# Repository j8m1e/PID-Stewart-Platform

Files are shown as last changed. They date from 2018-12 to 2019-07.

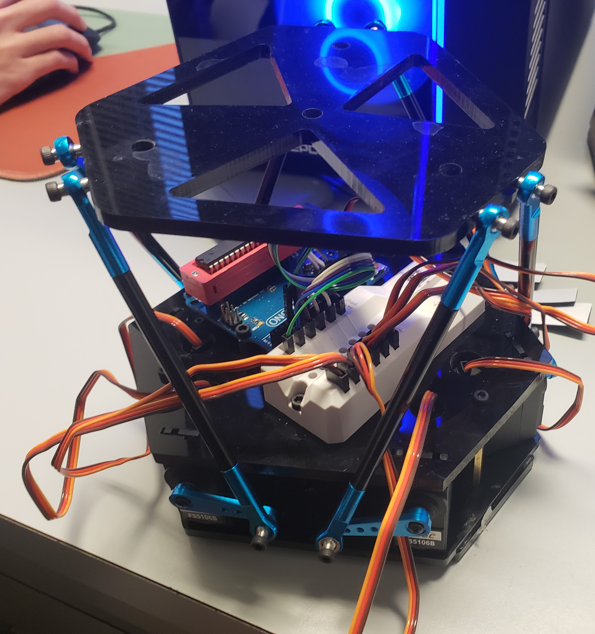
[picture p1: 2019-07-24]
Photos/In Progress.jpg

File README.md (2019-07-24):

# PID-Stewart-Platform

This project was submitted as part of the ECE 120 Honor Lab during the Fall semester of 2018. Originally inspired by a PID 6 degree of freedom Stewart Platform built by Full Motions Dynamics (https://youtu.be/j4OmVLc_oDw) our team of 3 wanted to accomplish something similar. Our design utilized 6 servo motors attached to a rectangular wooden base holding a touch resistive panel that tracks the relative location of a marble from the center. The location is relayed to an arduino which controlled the servos to tilt in the direction that balances the marble in the center of the platform. For the reverse kinematic arduino code, we ultimately ran out of time trying to implement a PID system instead having to opt for a trigonometric approximation. This along with the arduino crystal not refreshing fast enough ultimately led to the servo tilt overcompensating for locations relatively far from the center of the platform which can be seen in the demo video. More details are included in the Proposal and Final report.

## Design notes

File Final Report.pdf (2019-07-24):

Jamie Xu, Terence Lee, Kevin Wang

ECE 110 & 120 Honors Lab

tklee, chengx2, jiaenew2

# Stewart Platform Project Report

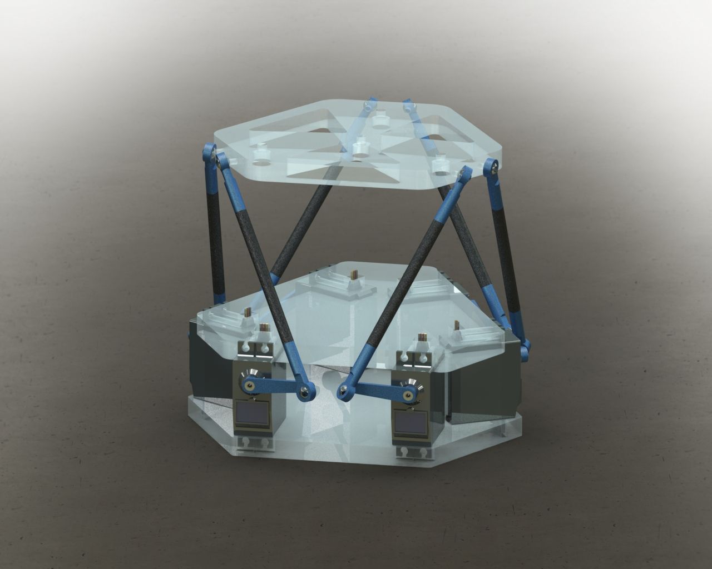
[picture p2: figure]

1. Introduction
1. Statement of Purpose
i. Our project involved building a six degree of freedom stewart platform.

This platform had data fed into the servos from a PID controller that was

fed data from a touch resistive panel to balance/center a metal ball bearing

when placed in a location other than the center of the platform. Our goal

for this project was to originally get the six degree of freedom stewart

platform functional because it can be applied to motion simulations.

2. Features and Benefits
i. As seen on the image provided in the cover page, the stewart platform

utilizes 6 servo motors attached to control rods that connect to a

acrylic+wooden base that houses the resistive panel.

2. Design
1. System Overview
i. For the block diagram, please refer to the Appendix below

ii. In the diagram, the output from the resistive panel (showing the x and y

coordinate of the ball bearing location) is fed into the controller which

calculates the desired servo position/angles to balance the bearing on the

center of the platform using a reverse kinematics algorithm. Once the six

servo angles are calculated, the data is fed into the servo motors which

then alters the pitch/roll/yaw of the resistive panel. This causes the ball bearing to shift to a new x and y coordinate which loops back into the

controller repeating this process indefinitely.

2. Design Details
i. Platform Design
1. The solidworks files designed can be accessed at this link:

https://bit.ly/2GlqSc8

This type of platform is so common that it is assigned the name

“stewart platform”, so there is no lack of documentation online.

We wanted to change some dimensions in our design to make

using commercial parts and manufacturing custom parts more

convenient, which means designing the platform ourselves in

solidworks and using laser cutters for some parts.

ii. Wiring

1. The wiring is really simple and an inclusion of a schematic

diagram will only make it seem more complicated than it is(I still

included it nevertheless). All the servo need to be powered by an

external power source, that means making an breakout board to

supply the extra power that the arduino cannot provide. The

breakout board consists of a 5v rail and a ground rail, powering all

the servos in parallel, and wires connecting each of the arduino’s

pwm out pins to the signal pins of the servos. One notable thing is

that the arduino, the breakout board, and the servos all need to be grounded together for the servos to work properly. We ended up

hand soldering a pcb for a more compact design.

2. Reverse Kinematic Calculations

Since for our purpose of balancing a ball bearing we only

need to consider the rotation of the platform (and not the

translation), the math can be simplified by pairing the two servos

that control the same point on the top platform. Given the

rotational angles in each axles, we can calculate the y coordinate of

the three attachment clusters on the top platform. And from the y

coordinates, by assuming the pair of servos have complementary

angles, we can calculate the angles by splitting the triangles in half

and using cos laws. All the calculations also only need to be

estimates because we are using a PID controller to control the

outputs.

3. Results
1. Test Video
i. https://youtu.be/KuF7Rv7t0T8
2. As can be seen in the video above, the PID stewart platform is functional and tilts

the platform in the correct direction albeit having some issues with over

approximations as well as the platform oscillating even after the ball bearing

reaches the center of the platform. Further analysis of these issues and possible

future solutions will be covered below.

4. Problems and Challenges
1. While working on this project, our group ran into several issues. After designing

the platform in Solidworks and cutting out the acrylic pieces for the platform

plates, a short destroyed the servos we were using and the new servos ordered had

slightly different dimensions and shape which meant redesigning the acrylic

plates to account for this. In addition to this, the socket was also fried in the short

which meant we had to rewire the circuitry and solder it to a perfboard.

2. After the platform was assembled and functional, our group ran into difficulty

getting the reverse kinematic arduino code working properly. The code we

originally planned on using turned out to be riddled with errors and would take

too much time to sort through. After struggling with finding the right data sheet

for the resistive panel and mapping its 4 wires properly, our group found a

relatively simpler reverse kinematic arduino code. Despite finding this, there was

an issue with the calculation that led to the servo angle position being inconsistent

despite being fed only a single value. Our group addressed this by analyzing the

Inverse Kinematics algorithm [4] and rewriting the calculation portion of the

code. The final result is shown in the video contained above.

3. There still remain some issues with the platform mainly that when placing the ball

bearing at larger distances from the center, the servo angle calculated is largely

overestimated regardless of the gain adjustments we made as well as a continuous

oscillation of the platform. In the future, the oscillation issue could be resolved by finding the ideal PID values for our system or using more than one set of PID

values for different error ranges.

5. Future Plans
1. In the future when our group has free time to work on this project, we would like

to look into adding the ability for the platform to run without being connected to a

power supply instead running off a li-po battery so that the platform is less

restricted. We could also tinker with the PID values a lot more so that we can

balance the ball within 1 or 2 oscillations. Fixing the oscillation of the servo arms

is as simple as switching to a board that has a faster crystal or more timers. Given

both time and motivation, our team wants to fix the arduino code so that the

platform can operate at full capacity.

6. References
1. [1]"Full Motion Dynamics", Full Motion Dynamics, 2018. [Online]. Available:

http://fullmotiondynamics.com/. [Accessed: 16- Dec- 2018].

2. [2]Full Motion Dynamics, Ball and Plate PID control with 6 DOF Stewart

platform. 2012.

3. [3]"Arduino controlled Rotary Stewart Platform", Makezilla, 2016. [Online].

Available:

http://makezilla.com/2016/01/30/arduino-controlled-rotary-stewart-platform/.

[Accessed: 16- Dec- 2018].

4. [4]"Inverse Kinematics: how to move a robotic arm (and why this is harder than it

seems) - Applied Go", Applied Go, 2016. [Online]. Available:

https://appliedgo.net/roboticarm/. [Accessed: 16- Dec- 2018].

5. [5]"Capacitive vs. Resistive Touch Panel - What feels better?", Mikroe.com,

2016. [Online]. Available:

https://www.mikroe.com/blog/capacitive-vs-resistive-touch-panel-feels-better.

[Accessed: 16- Dec- 2018].

## Appendix

Block Diagram:

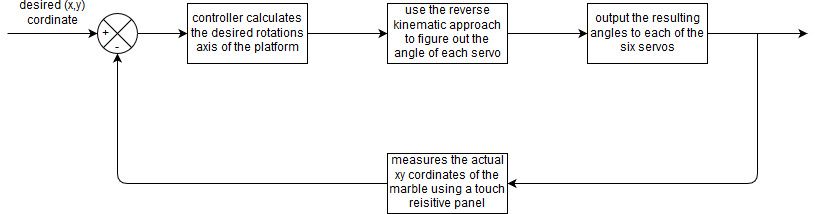
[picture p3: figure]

Wiring Diagram

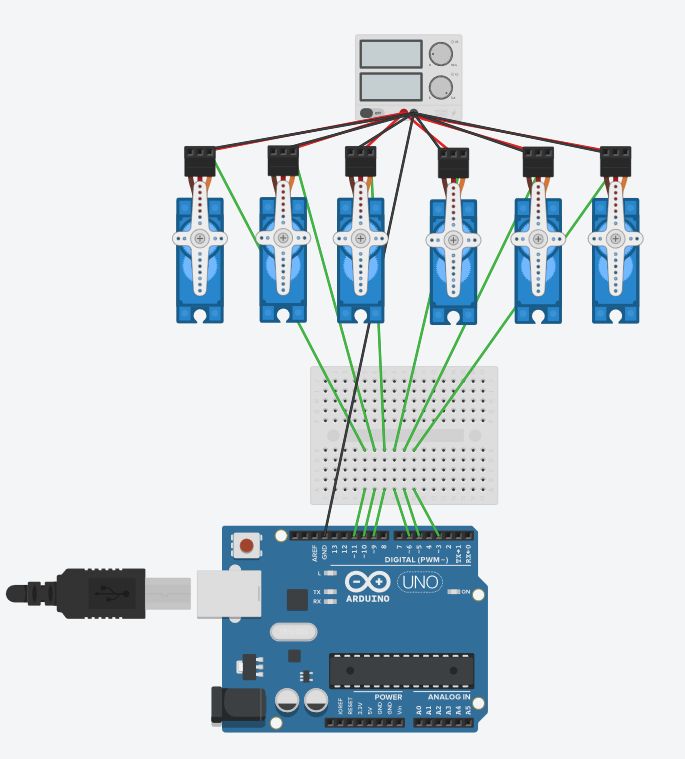
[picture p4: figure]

Code: https://github.com/j8m1e/PID-Stewart-Platform

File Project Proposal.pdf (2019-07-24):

Terence Lee, tklee3, ECE 120 Jia En Wang, jiaenew2, ECE 110 Cheng Xu, chengx2, ECE 110 & 120 ECE 110/120 Honors Lab Project Page
I. Introduction
A. Statement of Purpose
1. We are planning on building a six degree of freedom stewart platform. Currently we are fielding two different applications of the stewart platform each with different degrees of difficulty/time required. The first application would be connecting the platform to a racing simulator and replicating the movements of the vehicle onto the platform. The second application would be attaching a resistive touch panel and using the stewart platform to balance a marble. Once our team has a functional device, we plan on choosing one of the applications depending on the time remaining in the semester.
B. Background Research
1. Originally designed by Eric Gough in 1954, the stewart platform contains six actuators that allow for a plate placed on top that can be programmed to rotate three ways (pitch, roll, and yaw) to achieve 6 degrees of freedom simultaneously.
2. https://youtu.be/WmKnnp1xTPg
3. Simscape Multibody is a versatile platform which simulates 3d mechanical systems such as models like our stewart platforms or suspension and hydraulic models. We can use the simscape multibody stem to simulate the motion by representing the physical components as blocks. Additionally, we are able 3d models into Multibody and modify the schematic from there. Lastly, having some experience in Matlab will s facilitate the process in modifying the digital model. Another benefit of using multibody is the ability to simulate the different environments that our model will encounter such as the object type, DOF angles and severity of weight shift.

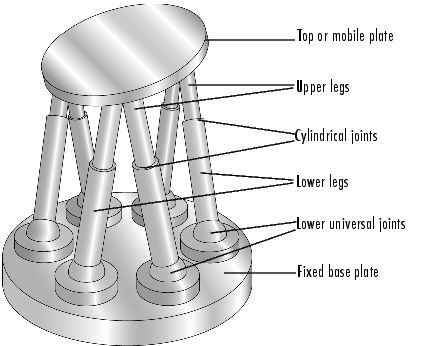
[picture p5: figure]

4.

5.

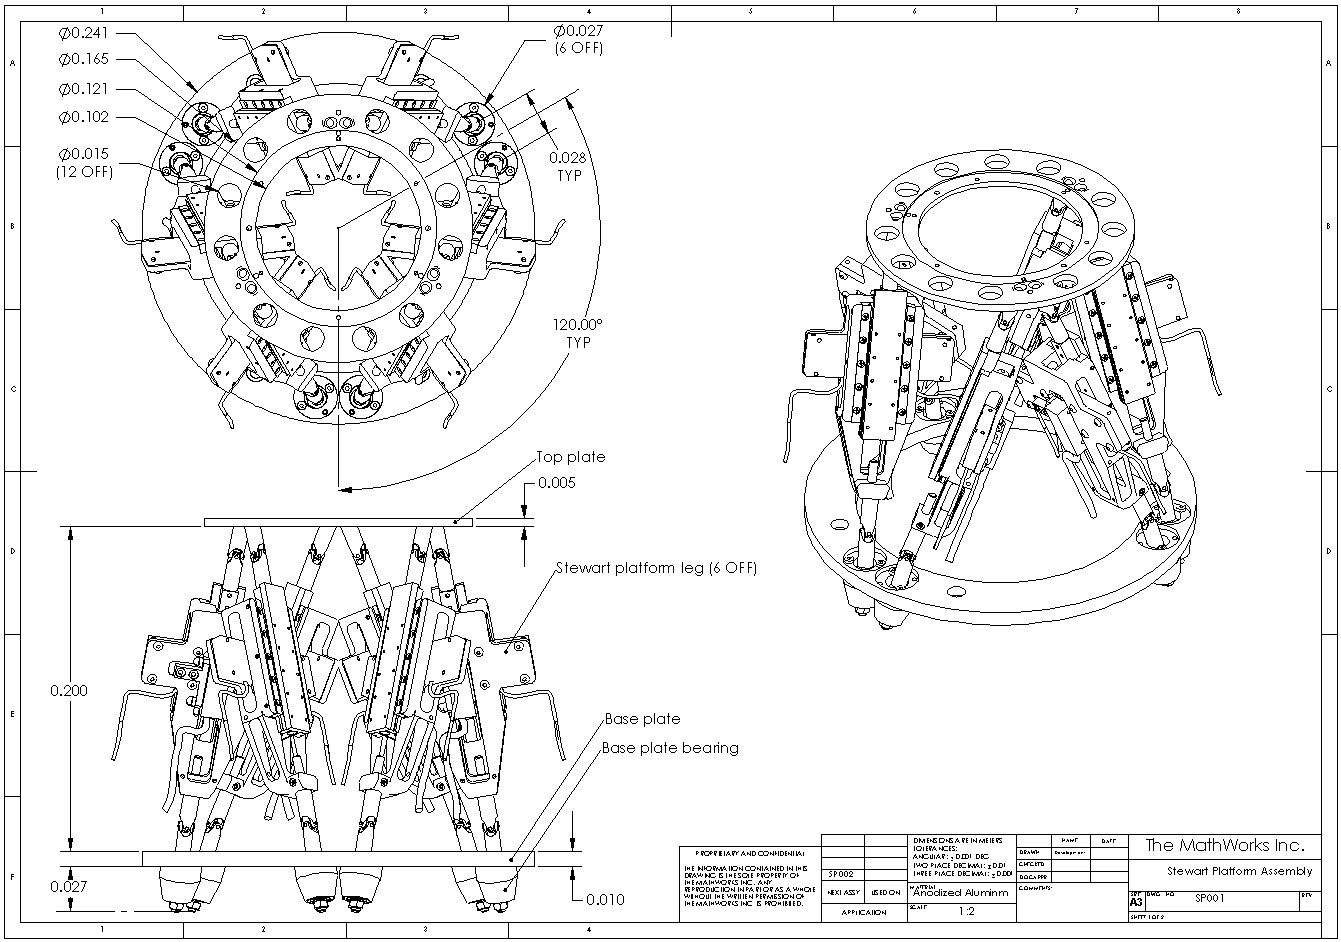
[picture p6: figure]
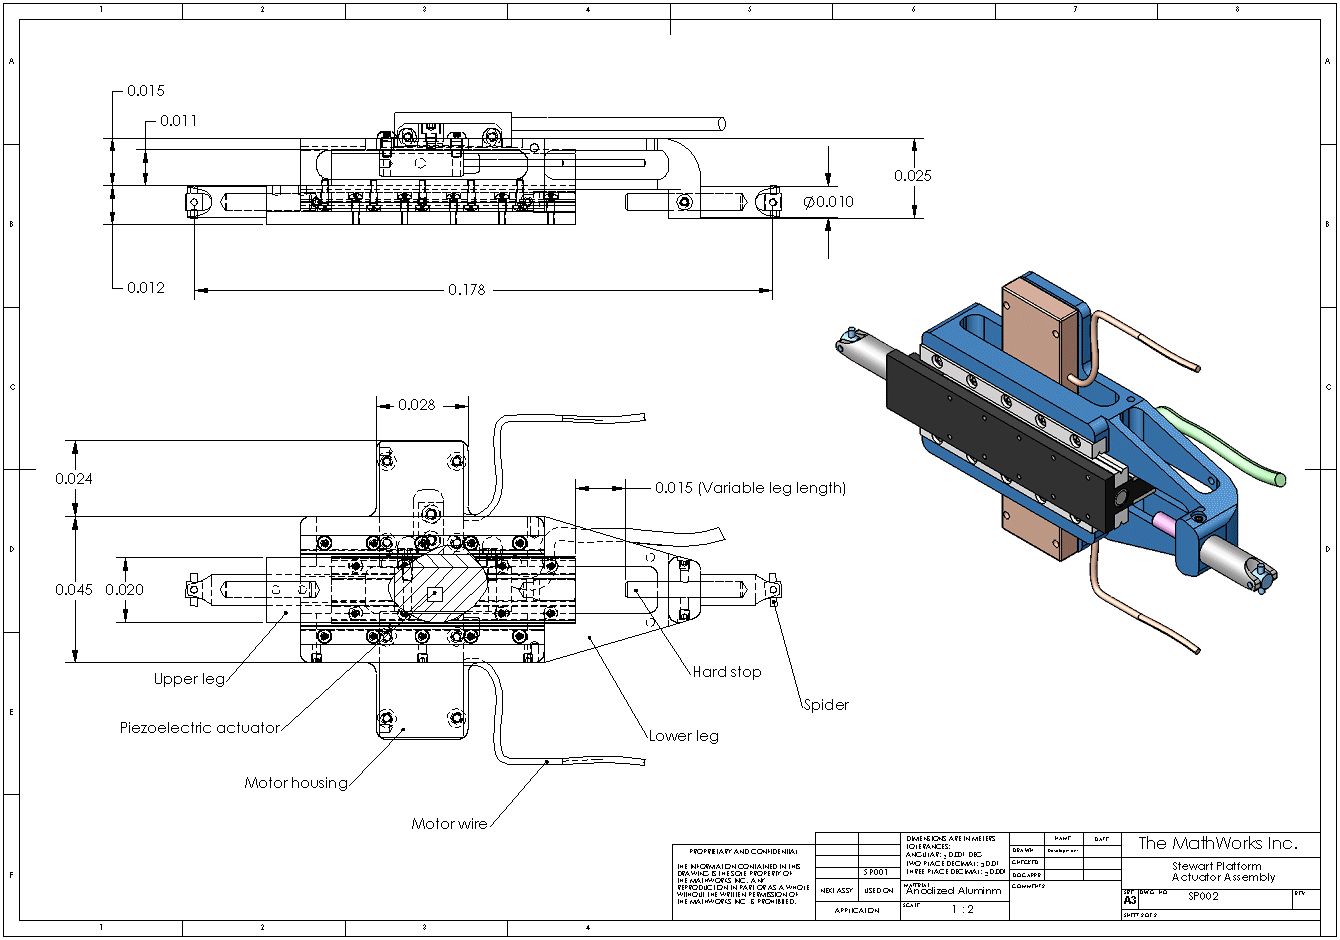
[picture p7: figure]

II. Design Details
A. Block Diagram/ Flow Chart

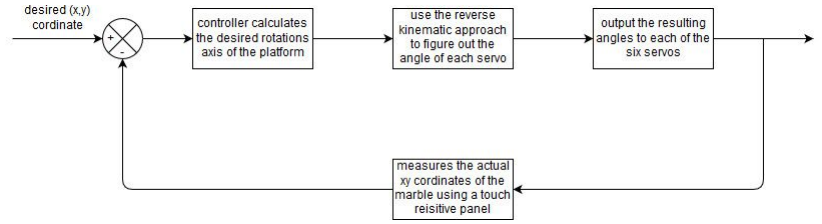
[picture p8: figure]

B. System Overview

1. We input a desired coordinate for the marble, and the controller calculates the difference in distance and angle between the actual position and the desired one. The controller then determines the axis of rotation and convert it into euler rotations. It then uses inverse kinematic approach to calculate the angle of each servos. After the servos are turned to the desired position, the resistive panel again measures the position of the marble and and feeds it back into a PID control loop.
III. | Parts ● 6*Servo - Hitec HS-425BB ● 1*ATMega328P ● various laser cut pieces ● ZIF Socket 28-Pin 0.3" ● DIP Sockets Solder Tail - 28-Pin 0.3" ● Solder-able Breadboard ● 6*end control rod ● Touch Resistive panel
IV. | Design
A. (1st Iteration Fusion)

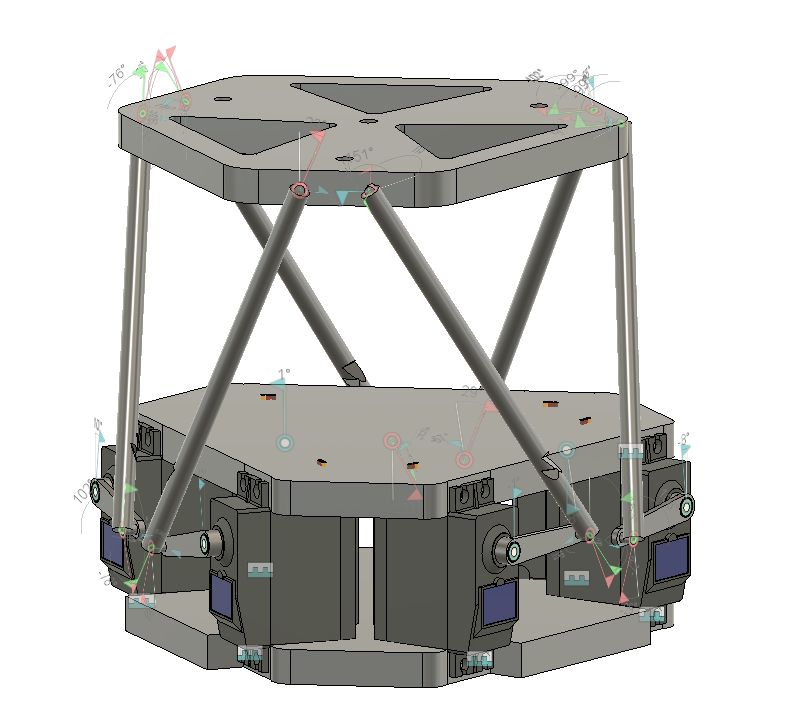
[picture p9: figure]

B. (2nd Iteration Solidworks)
V. Possible Challenges
A. Please list some of the challenges that your group foresee in working on your project.
1. One of the more significant challenges that our group may face are the programming tasks. We will be able to use libraries but we will need to manually develop the code ourselves. We must collaborate by understanding how the code harmonizes to create a functioning stewart-platform. We need to at least understand the fundamentals in how the program works so that we can identify issues quickly and mitigate them with precision.
2. Another potential issue we see arising is the physical process of building the machine itself. Many times, physical components are constructed incorrectly such as when wires are reversed or when rods are connected to the wrong slots. Additionally, some of the components listed are quite fragile so our group will need to take great care in making sure we do not damage or break any components to keep costs down.
3. Financial costs are an essential part of any ece project but our stewart platform is simple yet functional. Total costs will hover around the two hundred dollar range plus or minus a few dozen dollars.
4. Lastly, scaling is a substantial issue where we need to make sure that our model is proportional in size in relation to a full scale stewart-platform. Scaling is a significant issue to tackle because we need to make sure we get the balance right in order for the platform to stabilize objects on the glass display. If we don’t get scaling right, physical properties may be shifted and our stewart platform may not be well balanced.
VI. References
A. D. Stewart, "A Platform with Six Degrees of Freedom", Aircraft Engineering and
| Aerospace Technology, vol. 38, no. 4, pp. 30-35, 1966.
B. V. Gough, "Contribution to discussion of papers on research in Automobile
| Stability, Control and Tyre performance", Proc. Auto Div Inst. Mech. ENg., vol. 392-394, 1956.
C. "About the Stewart Platform- MATLAB & Simulink", Mathworks.com, 2018.
| [Online]. Available: https://www.mathworks.com/help/physmod/sm/mech/ug/about-the-stewart-platfor m.html. [Accessed: 16- Sep- 2018]

Links:
- http://fullmotiondynamics.com/
- https://github.com/tcleg/Six_Axis_Complementary_Filter
- https://www.youtube.com/watch?v=j4OmVLc_oDw
- http://makezilla.com/2016/01/30/arduino-controlled-rotary-stewart-platform/
- https://appliedgo.net/roboticarm/
- https://www.mikroe.com/blog/capacitive-vs-resistive-touch-panel-feels-better

Github Repositories

https://github.com/ThomasKNR/RotaryStewartPlatformhttps://github.com/MarginallyClever/Rotary-Stewart-Platform-2-firmwarehttps://github.com/patrickLangan/stewartPlatf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

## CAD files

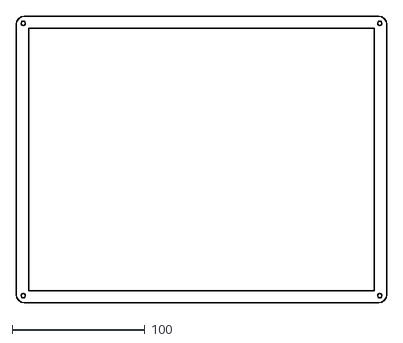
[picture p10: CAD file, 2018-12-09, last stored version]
stewy-master/doc/CAD files/DXF/ts_platform_over.dxf
279.4 x 215.9

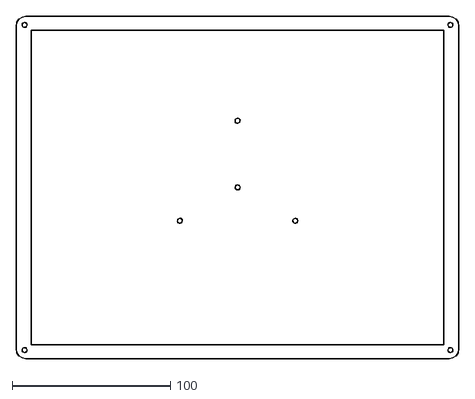
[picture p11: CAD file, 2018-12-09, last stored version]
stewy-master/doc/CAD files/DXF/ts_platform_under.dxf
279.4 x 215.9

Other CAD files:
stewy-master/doc/CAD files/DXF/base_bottom.dxf
stewy-master/doc/CAD files/DXF/base_top.dxf
stewy-master/doc/CAD files/DXF/platform_large.dxf
stewy-master/doc/CAD files/DXF/platform_small.dxf

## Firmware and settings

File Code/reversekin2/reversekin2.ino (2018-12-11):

#include <Servo.h>

//MIN and MAX PWM pulse sizes, they can be found in servo documentation
#define MAX 2200
#define MIN 800

//Positions of servos mounted in opposite direction
#define INV1 1
#define INV2 3
#define INV3 5

//constants for computation of positions of connection points
#define pi  3.14159
#define deg2rad 180/pi
#define deg30 pi/6





//Array of servo objects
Servo servo[6];
//Zero positions of servos, in this positions their arms are perfectly horizontal, in us
static int zero[6]={1475,1470,1490,1480,1460,1490};
//In this array is stored requested position for platform - x,y,z,rot(x),rot(y),rot(z)
static float arr[6]={0,0,0, radians(0),radians(0),radians(0)};
//Actual degree of rotation of all servo arms, they start at 0 - horizontal, used to reduce
//complexity of calculating new degree of rotation
static float theta_a[6]={0.0,0.0,0.0, 0.0,0.0,0.0};
//Array of current servo positions in us
static int servo_pos[6];
//rotation of servo arms in respect to axis x
const float beta[] = {pi/2,-pi/2,-pi/6, 5*pi/6,-5*pi/6,pi/6},
//maximum servo positions, 0 is horizontal position
      servo_min=radians(-80),servo_max=radians(80),
//servo_mult - multiplier used for conversion radians->servo pulse in us
//L1-effective length of servo arm, L2 - length of base and platform connecting arm
//z_home - height of platform above base, 0 is height of servo arms
servo_mult=400/(pi/4),L1 = 30,L2 = 120, z_home = 105;
//RD distance from center of platform to attachment points (arm attachment point)
//RD distance from center of base to center of servo rotation points (servo axis)
//theta_p-angle between two servo axis points, theta_r - between platform attachment points
//theta_angle-helper variable
//p[][]=x y values for servo rotation points
//re[]{}=x y z values of platform attachment points positions
//equations used for p and re will affect postion of X axis, they can be changed to achieve
//specific X axis position
const float RD = 73,PD =85,theta_p = radians(23.2),
theta_angle=(pi/3-theta_p)/2, theta_r = radians(8),
      p[2][6]={
          {
            -PD*cos(deg30-theta_angle),-PD*cos(deg30-theta_angle),
            PD*sin(theta_angle),PD*cos(deg30+theta_angle),
            PD*cos(deg30+theta_angle),PD*sin(theta_angle)
         },
         {
            -PD*sin(deg30-theta_angle),PD*sin(deg30-theta_angle),
            PD*cos(theta_angle),PD*sin(deg30+theta_angle),
            -PD*sin(deg30+theta_angle),-PD*cos(theta_angle)
         }
      },
      re[3][6] = {
          {
              -RD*sin(deg30+theta_r/2),-RD*sin(deg30+theta_r/2),
              -RD*sin(deg30-theta_r/2),RD*cos(theta_r/2),
              RD*cos(theta_r/2),-RD*sin(deg30-theta_r/2),
          },{
              -RD*cos(deg30+theta_r/2),RD*cos(deg30+theta_r/2),
              RD*cos(deg30-theta_r/2),RD*sin(theta_r/2),
              -RD*sin(theta_r/2),-RD*cos(deg30-theta_r/2),
          },{
              0,0,0,0,0,0
          }
};
//arrays used for servo rotation calculation
//H[]-center position of platform can be moved with respect to base, this is
//translation vector representing this move
static float M[3][3], rxp[3][6], T[3], H[3] = {0,0,z_home};

void setup(){
//attachment of servos to PWM digital pins of arduino
   servo[0].attach(3, MIN, MAX);
   servo[1].attach(5, MIN, MAX);
   servo[2].attach(6, MIN, MAX);
   servo[3].attach(9, MIN, MAX);
   servo[4].attach(10, MIN, MAX);
   servo[5].attach(11, MIN, MAX);
//begin of serial communication
   Serial.begin(9600);
//putting into base position
   setPos(arr);
}

//function calculating needed servo rotation value
float getAlpha(int *i){
   static int n;
   static float th=0;
   static float q[3], dl[3], dl2;
   double min=servo_min;
   double max=servo_max;
   n=0;
   th=theta_a[*i];
   while(n<20){
    //calculation of position of base attachment point (point on servo arm where is leg connected)
      q[0] = L1*cos(th)*cos(beta[*i]) + p[0][*i];
      q[1] = L1*cos(th)*sin(beta[*i]) + p[1][*i];
      q[2] = L1*sin(th);
    //calculation of distance between according platform attachment point and base attachment point
      dl[0] = rxp[0][*i] - q[0];
      dl[1] = rxp[1][*i] - q[1];
      dl[2] = rxp[2][*i] - q[2];
      dl2 = sqrt(dl[0]*dl[0] + dl[1]*dl[1] + dl[2]*dl[2]);
    //if this distance is the same as leg length, value of theta_a is corrent, we return it
      if(abs(L2-dl2)<0.01){
         return th;
      }
    //if not, we split the searched space in half, then try next value
      if(dl2<L2){
         max=th;
      }else{
         min=th;
      }
      n+=1;
      if(max==servo_min || min==servo_max){
         return th;
      }
      th = min+(max-min)/2;
   }
   return th;
}

//function calculating rotation matrix
void getmatrix(float pe[])
{
   float psi=pe[5];
   float theta=pe[4];
   float phi=pe[3];
   M[0][0] = cos(psi)*cos(theta);
   M[1][0] = -sin(psi)*cos(phi)+cos(psi)*sin(theta)*sin(phi);
   M[2][0] = sin(psi)*sin(phi)+cos(psi)*cos(phi)*sin(theta);

   M[0][1] = sin(psi)*cos(theta);
   M[1][1] = cos(psi)*cos(phi)+sin(psi)*sin(theta)*sin(phi);
   M[2][1] = cos(theta)*sin(phi);

   M[0][2] = -sin(theta);
   M[1][2] = -cos(psi)*sin(phi)+sin(psi)*sin(theta)*cos(phi);
   M[2][2] = cos(theta)*cos(phi);
}
//calculates wanted position of platform attachment poins using calculated rotation matrix
//and translation vector
void getrxp(float pe[])
{
   for(int i=0;i<6;i++){
      rxp[0][i] = T[0]+M[0][0]*(re[0][i])+M[0][1]*(re[1][i])+M[0][2]*(re[2][i]);
      rxp[1][i] = T[1]+M[1][0]*(re[0][i])+M[1][1]*(re[1][i])+M[1][2]*(re[2][i]);
      rxp[2][i] = T[2]+M[2][0]*(re[0][i])+M[2][1]*(re[1][i])+M[2][2]*(re[2][i]);
   }
}
//function calculating translation vector - desired move vector + home translation vector
void getT(float pe[])
{
   T[0] = pe[0]+H[0];
   T[1] = pe[1]+H[1];
   T[2] = pe[2]+H[2];
}

unsigned char setPos(float pe[]){
    unsigned char errorcount;
    errorcount=0;
    for(int i = 0; i < 6; i++)
    {
        getT(pe);
        getmatrix(pe);
        getrxp(pe);
        theta_a[i]=getAlpha(&i);
        if(i==INV1||i==INV2||i==INV3){
            servo_pos[i] = constrain(zero[i] - (theta_a[i])*servo_mult, MIN,MAX);
        }
        else{
            servo_pos[i] = constrain(zero[i] + (theta_a[i])*servo_mult, MIN,MAX);
        }
        servo[i].writeMicroseconds(servo_pos[i]);
    }


    return errorcount;
}



//main control loop, obtain requested action from serial connection, then execute it
void loop()
{

   if(Serial.available()>0){
      int input=Serial.read();
//      switch(input){

//action to change position of platform, obtain 6 values representing desired position
            for(int i=0;i<6;i++){
               long kk;
               while(Serial.available()<4){
                  ;
              
               kk=(long)Serial.read();
               kk=kk+(Serial.read()<<8);
               kk=kk+(Serial.read()<<16);
               kk=kk+(Serial.read()<<24);
               if(i<3){
                  arr[i]=(kk/100);
               }else{
                  arr[i]=radians(kk/100.0);
               }
            }
            Serial.write(setPos(arr));
            Serial.flush();
            break;
            for(int i = 0; i < 6; i++){
              Serial.print(servo_pos[i]);
              Serial.print("    ");
              if(i==5) {
               Serial.println();
               }
             
 //   }
      }
      }
   }
}

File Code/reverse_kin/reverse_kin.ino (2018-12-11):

#include <Servo.h>
const float pi = 3.14159, theta_r = radians(48.0), theta_p = radians(23.2), theta_s[] = {-pi/3,2*pi/3, pi, 0, pi/3, -2*pi/3},
RD = 73, PD = 85, L1 = 30, L2 = 120, z_home = 105, servo_min = -90, servo_max = 90,servo_mult = 55 ,
p[2][6] = {{PD*cos(pi/6 + theta_p), PD*cos(pi/6 - theta_p), PD*cos(-(pi/2 - theta_p)),-PD*cos(-(pi/2 - theta_p)), -PD*cos(pi/6 - theta_p), -PD*cos(pi/6 + theta_p)},
          {PD*sin(pi/6 + theta_p), PD*sin(pi/6 - theta_p), PD*sin(-(pi/2 - theta_p)),PD*sin(-(pi/2 - theta_p)), PD*sin(pi/6 - theta_p), PD*sin(pi/6 + theta_p)}},
re[2][6] = {{RD*cos(pi/6 + theta_r), RD*cos(pi/6 - theta_r), RD*cos(-(pi/2 - theta_r)),-RD*cos(-(pi/2 - theta_r)), -RD*cos(pi/6 - theta_r), -RD*cos(pi/6 + theta_r)},
           {RD*sin(pi/6 + theta_r), RD*sin(pi/6 - theta_r), RD*sin(-(pi/2 - theta_r)),RD*sin(-(pi/2 - theta_r)), RD*sin(pi/6 - theta_r), RD*sin(pi/6 + theta_r)}};
/*
theta_r = angle between attachment points
theta_p = angle between rotation points
theta_s = orientation of the servos
RD = distance to end e
ector attachment points
PD = distance to servo rotation points
L1 = servo arm length
L2 = connecting arm length
z_home = default z height with servo arms horizontal
servo_min = lower limit for servo arm angle
servo_max = upper limit for servo arm angle
servo_mult = multiplier to convert to milliseconds
p = location of servo rotation points in base frame [x/y][1-6]
re = location of attachment points in end e
ector frame [x/y][1-6]
*/
const int servo_pin[6] = {9,3, 5, 11, 6, 10}, servo_zero[6] = {1500, 1500, 1500, 1500, 1500, 1500};
/*
servo_pin = servo pin assignments,
servo_zero = zero angles for each servo (horizontal)
*/
Servo servo[6];
/*
Servos 0, 2, 4: reversed (+ = down, - = up)
Servos 1, 3, 5: normal (+ = up, - = down)
*/
void setup()
{
  Serial.begin(9600);
  for(int i = 0; i < 6; i++)
    {
    servo[i].attach(servo_pin[i]);
    servo[i].writeMicroseconds(servo_zero[i]);
    }
  delay(100);
}
void loop()
  {
  /*  float z = 0;
  while(!Serial.available()){
  }
  z = Serial.read();
  Serial.print(z);
  */
  static float pe[6] = {0,0,10,radians(0),radians(0),radians(0)}, theta_a[6], servo_pos[6],q[3][6], r[3][6], dl[3][6], dl2[6];
  /*
  pe = location and orientation of end effector frame relative to the base frame [sway, surge,heave, pitch, roll, yaw)
  theta_a = angle of the servo arm
  servo_pos = value written to each servo
  q = position of lower mounting point of connecting link [x,y,x][1-6]
  r = position of upper mounting point of connecting link
  dl = di
erence between x,y,z coordinates of q and r
  dl2 = distance between q and r
  */
  for(int i = 0; i < 6; i++)
    {

     int n=0;
      float min=servo_min;
      float max=servo_max;
      while(n<10){
//      Serial.print(n);
      q[0][i] = L1*cos(-theta_a[i])*cos(theta_s[i]) + p[0][i];
      q[1][i] = L1*cos(-theta_a[i])*sin(theta_s[i]) + p[1][i];
      q[2][i] = -L1*sin(-theta_a[i]);
      r[0][i] = re[0][i]*cos(pe[4])*cos(pe[5]) + re[1][i]*(sin(pe[3])*sin(pe[4])*cos(pe[5]) - cos(pe[3])*sin(pe[5])) + pe[0];
      r[1][i] = re[0][i]*cos(pe[4])*sin(pe[5]) + re[1][i]*(cos(pe[3])*cos(pe[5]) + sin(pe[3])*sin(pe[4])*sin(pe[5])) + pe[1];
      r[2][i] = -re[0][i]*sin(pe[4]) + re[1][i]*sin(pe[3])*cos(pe[4]) + z_home + pe[2];
      dl[0][i] = q[0][i] - r[0][i];
      dl[1][i] = q[1][i] - r[1][i];
      dl[2][i] = q[2][i] - r[2][i];
      dl2[i] = sqrt(dl[0][i]*dl[0][i] + dl[1][i]*dl[1][i] + dl[2][i]*dl[2][i]) - L2;

if(abs(dl2[i])<0.1){
         theta_a[i]=theta_a[i];
      }
    else{
      if(dl2[i]<0){
         max=theta_a[i];
      }
      else{
         min=theta_a[i];
      }
      n++;
      
      if(max==servo_min || min==servo_max){
         theta_a[i]=theta_a[i];
      }
      else{
      theta_a[i] = min+(max-min)/2;
      }
   }
      }

      //define direction of rotation
      theta_a[i] = constrain(theta_a[i], servo_min, servo_max);
      if(i%2 == 1) 
      {
        servo_pos[i] = servo_zero[i] + theta_a[i]*servo_mult;
      }
      else 
      {
        servo_pos[i] = servo_zero[i] - theta_a[i]*servo_mult;
      }
    }
    //write the angels to the servo
  for(int i = 0; i < 6; i++)
    {
    Serial.print(servo_pos[i]);
    Serial.print("    ");
    if(i==5) 
    {
      Serial.println();
    }
    servo[i].writeMicroseconds(servo_pos[i]);
    }
  }

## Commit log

2018-12-09 Added reverse kin and touch screen files
    [reverse_kin.ino, touch_screen.ino]
2018-12-09 Addded stewy-master project
    [BOM.xlsx, StewartPlatformSimulator_v2.xlsm, base_bottom.dxf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]
2018-12-10 Changed formatting on reverse kin
    [reverse_kin.ino]
2019-07-24 Updated README and added demo video file
    [BOM.xlsx, StewartPlatformSimulator_v2.xlsm, base_bottom.dxf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]
